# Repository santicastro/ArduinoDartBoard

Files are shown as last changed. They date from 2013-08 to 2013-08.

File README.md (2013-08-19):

ArduinoDartsBoard
=================

Electronic darts board controlled by Arduino Mini Pro. It's o a very early development status. Only cricket game is implemented and has some bugs.

I built the software and the pcb from scratch. I'll upload the pcb diagrams as soon as I can.

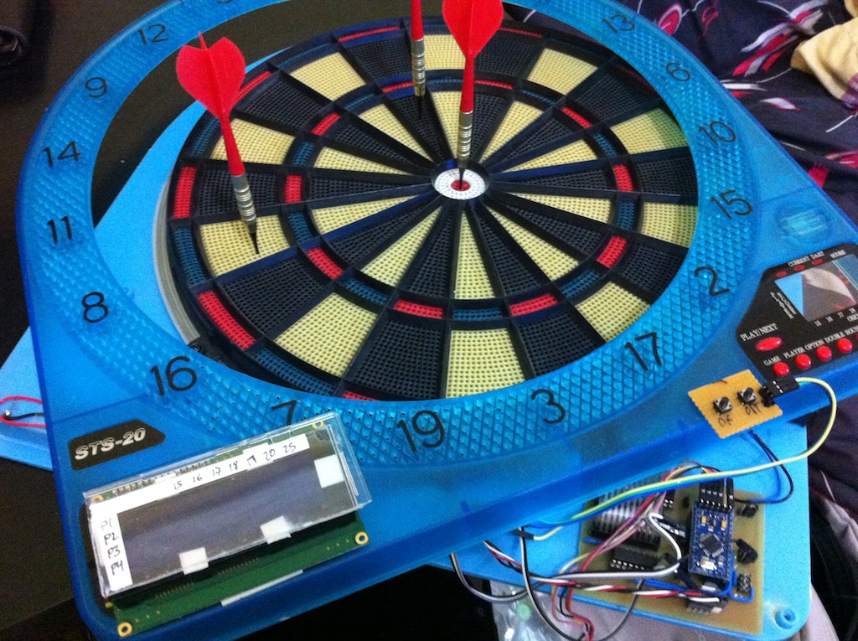
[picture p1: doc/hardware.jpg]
hardware

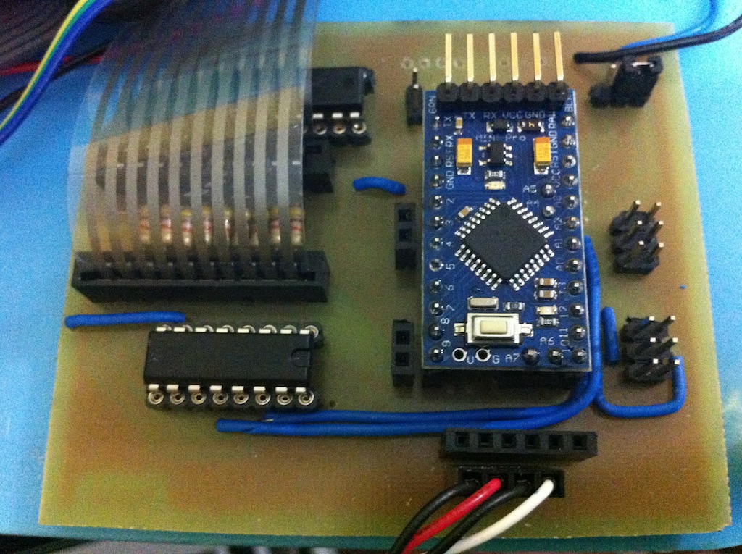
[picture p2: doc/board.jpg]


Sample of the game finished melody: http://www.youtube.com/watch?v=AD7XjPF0V5o

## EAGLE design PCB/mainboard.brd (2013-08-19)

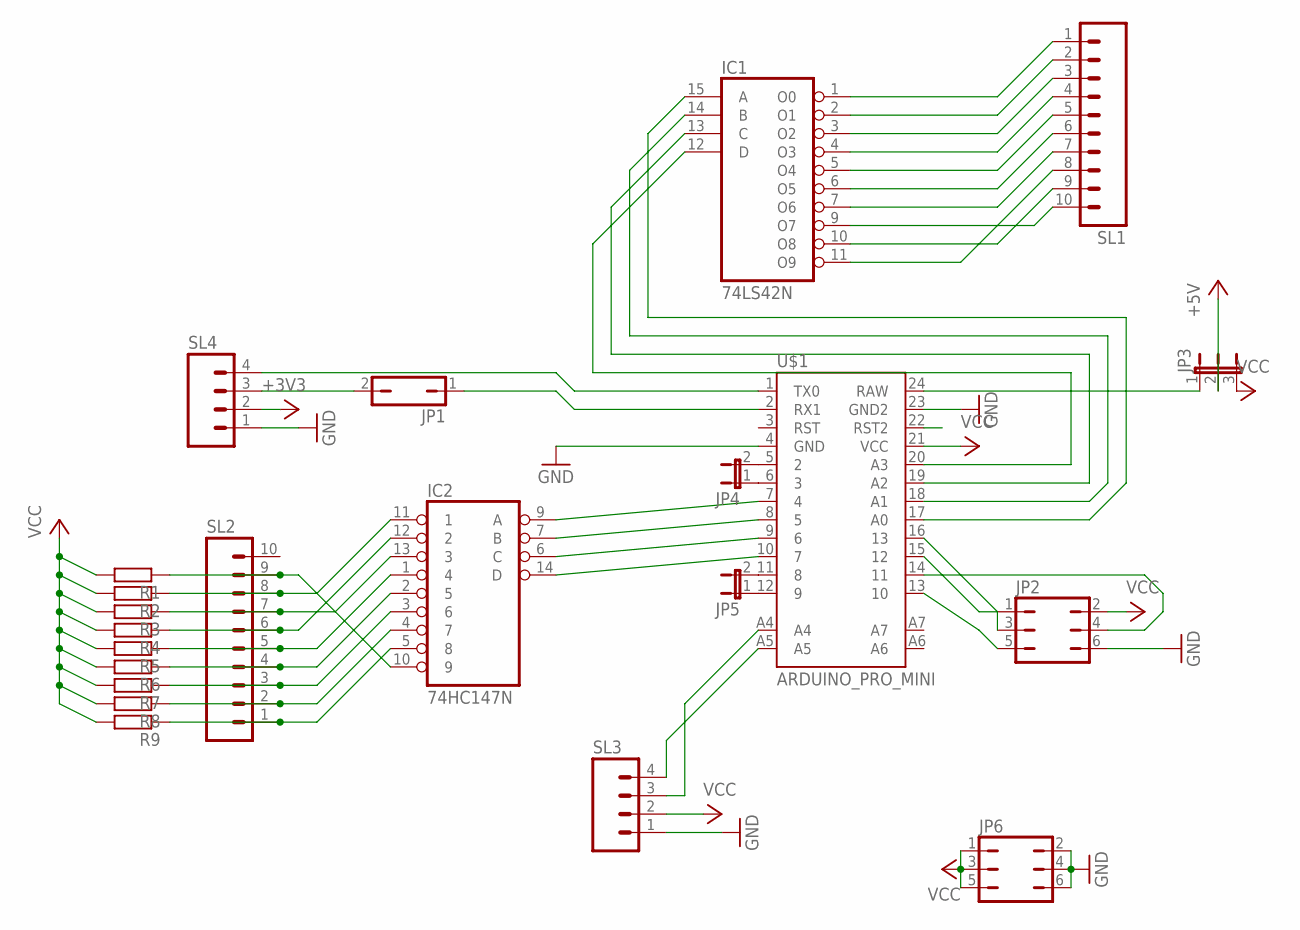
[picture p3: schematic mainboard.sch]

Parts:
IC1: 74LS42N; DIL16
IC2: 74HC147N; DIL16
JP1: JP1Q; JP1
JP2, JP6: JP3Q
JP3: JP2E; JP2
JP4, JP5: JP1E; JP1
R1, R2, R3, R4, R5, R6, R7, R8, R9: R-EU_0204/7; 0204/7
SL1, SL2: M10; 10P
SL3, SL4: M04; 04P
U$1: ARDUINO_PRO_MINI

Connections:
+3V3: SL4.2
+5V: JP3.2
GND: IC1.8 (GND), IC2.8 (GND), JP2.6, JP6.2, JP6.4, JP6.6, SL3.1, SL4.1, U$1.4 (GND), U$1.23 (GND2)
unnamed: IC2.2 (5), R6.1, SL2.4
unnamed: IC2.1 (4), R5.1, SL2.5
unnamed: IC2.12 (2), R4.1, SL2.6
unnamed: IC2.5 (8), R9.1, SL2.1
unnamed: IC2.4 (7), R8.1, SL2.2
unnamed: IC2.3 (6), R7.1, SL2.3
unnamed: IC2.13 (3), R3.1, SL2.7
unnamed: IC2.11 (1), R2.1, SL2.8
unnamed: IC2.10 (9), R1.1, SL2.9
unnamed: IC1.15 (A), U$1.17 (A0)
unnamed: IC1.14 (B), U$1.18 (A1)
unnamed: IC1.13 (C), U$1.19 (A2)
unnamed: IC1.12 (D), U$1.20 (A3)
unnamed: IC1.9 (O7), SL1.10
unnamed: IC1.10 (O8), SL1.9
unnamed: IC1.11 (O9), SL1.8
unnamed: IC2.9 (A), U$1.7 (4)
unnamed: IC1.1 (O0), SL1.1
unnamed: IC1.2 (O1), SL1.2
unnamed: IC1.3 (O2), SL1.3
unnamed: IC1.4 (O3), SL1.4
unnamed: IC1.5 (O4), SL1.5
unnamed: IC1.6 (O5), SL1.6
unnamed: IC1.7 (O6), SL1.7
unnamed: IC2.7 (B), U$1.8 (5)
unnamed: IC2.6 (C), U$1.9 (6)
unnamed: IC2.14 (D), U$1.10 (7)
unnamed: SL3.4, U$1.A5
unnamed: SL3.3, U$1.A4
unnamed: SL4.4, U$1.1 (TX0)
unnamed: JP1.2, SL4.3
unnamed: JP1.1, U$1.2 (RX1)
unnamed: JP2.1, U$1.15 (12)
unnamed: JP2.3, U$1.16 (13)
unnamed: JP2.5, U$1.13 (10)
unnamed: JP2.4, U$1.14 (11)
unnamed: JP3.1, U$1.24 (RAW)
unnamed: JP4.1, U$1.6 (3)
unnamed: JP4.2, U$1.5 (2)
unnamed: JP5.1, U$1.12 (9)
unnamed: JP5.2, U$1.11 (8)
VCC: IC1.16 (VCC), IC2.16 (VCC), JP2.2, JP3.3, JP6.1, JP6.3, JP6.5, R1.2, R2.2, R3.2, R4.2, R5.2, R6.2, R7.2, R8.2, R9.2, SL3.2, U$1.21 (VCC)

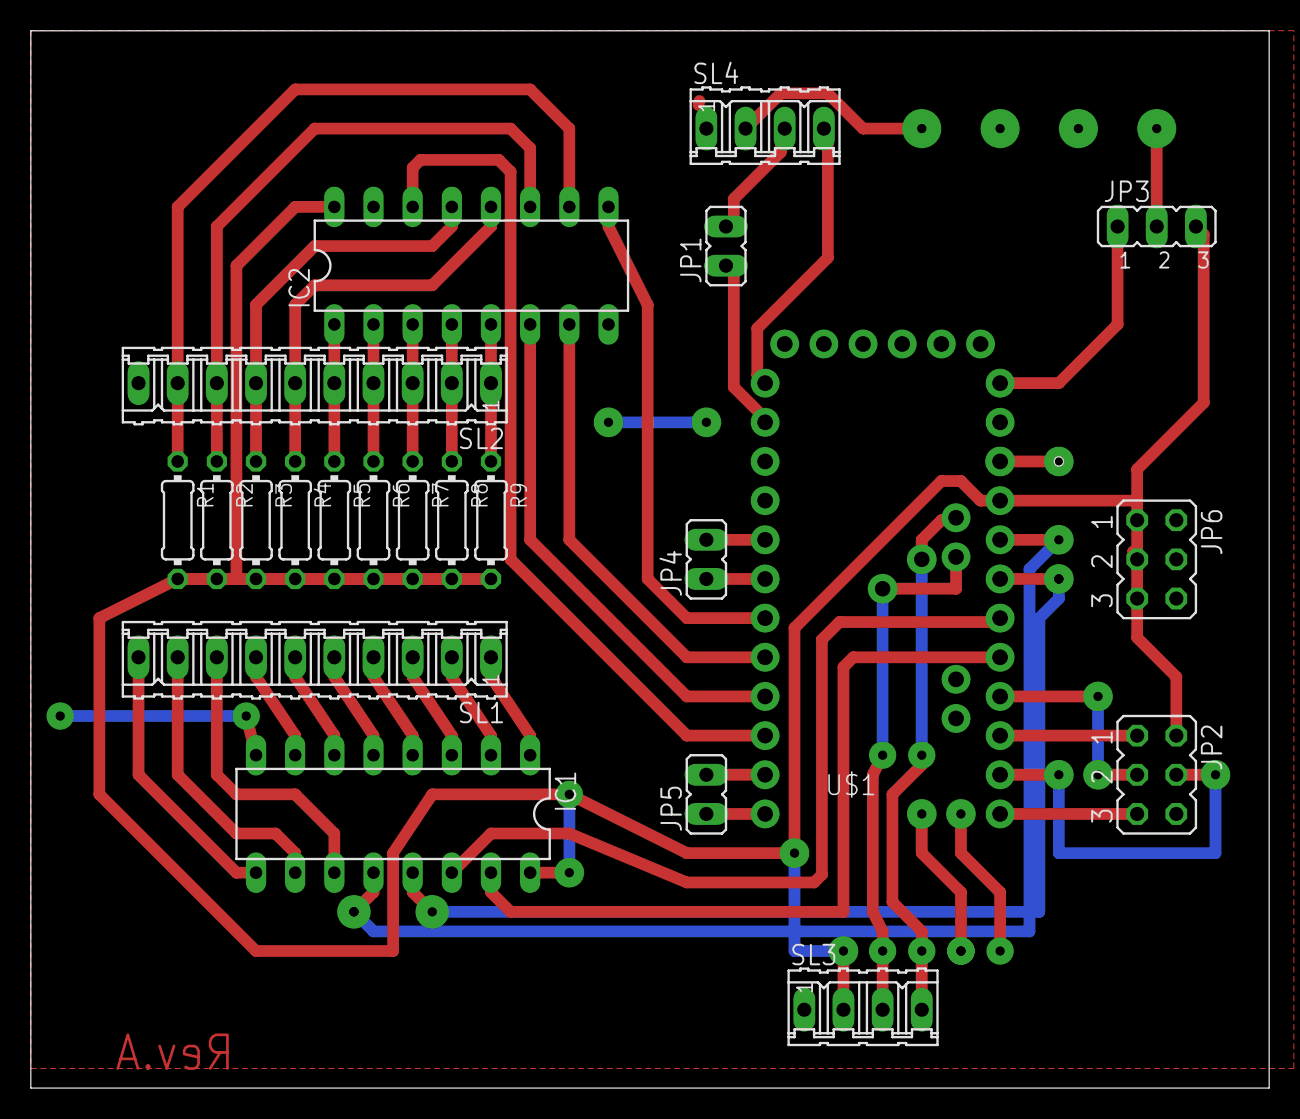
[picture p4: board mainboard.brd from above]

Board: 2 copper layers, 80.3 x 68.6 mm, 22 parts (0 on the bottom side), 43 nets.

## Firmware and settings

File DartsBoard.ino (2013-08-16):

#include <LiquidCrystal.h>
#include <Wire.h>

const int NONE=0;

int inPins[] = {
  4, 5, 6, 7};
int outPins[] = {
  A0, A1, A2, A3};


typedef struct button {
  byte value;
  byte type;
};

// type values are
#define DOUBLE_BUTTON 1
#define TRIPLE_BUTTON 2
#define NORMAL_BUTTON 4
#define INTERNAL_BUTTON 12 //8 + 4, so it's also normal button
#define EXTERNAL_BUTTON 20 // 16 + 4

struct button buttons[169];

int player_count = 2, current_player;

LiquidCrystal lcd(0x0);

byte char_0_hits[8] = { 
  B00000, B00000, B00000, B00000, B00000, B00000, B00000, B00000 };
byte char_1_hits[8] = { 
  B10000, B01000, B01000, B00100, B00100, B00010, B00010, B00001 };
byte char_2_hits[8] = { 
  B10001, B01010, B01010, B00100, B00100, B01010, B01010, B10001 };
byte char_3_hits[8] = { 
  B11111, B11011, B11011, B10101, B10101, B11011, B11011, B11111 };
byte char_selection[8] = { 
  B10000, B01000, B00100, B00010, B00010, B00100, B01000, B10000 };
byte char_dart[8] = { 
  B01010, B11011, B01110, B01110, B01110, B01110, B00100, B00100 };
#define SELECTION_CHAR 4
#define DART_CHAR 5

#define BUTTON_NEXT 2
#define BUTTON_OPTION 3
void setup() {
  int i;
  for(i=0; i<4; i++){
    pinMode(outPins[i], OUTPUT);
    pinMode(inPins[i], INPUT);
  }
  pinMode(BUTTON_NEXT, INPUT);
  digitalWrite(BUTTON_NEXT, HIGH);
  pinMode(BUTTON_OPTION, INPUT);
  digitalWrite(BUTTON_OPTION, HIGH);
  Serial.begin(9600);
  Serial.println("started");

  lcd.begin(20, 4);
  lcd.createChar(0, char_0_hits);
  lcd.createChar(1, char_1_hits);
  lcd.createChar(2, char_2_hits);
  lcd.createChar(3, char_3_hits);
  lcd.createChar(SELECTION_CHAR, char_selection);
  lcd.createChar(DART_CHAR, char_dart);

  lcd.setCursor(0,0);
  lcd.print("-= Darts =-");

  setupButtonMatrix();

  setupSounds();
  // playWin();
  //mapButtons();
  startGame();
}

int readButtons(){
  if(digitalRead(BUTTON_NEXT)==LOW){
    return BUTTON_NEXT;
  }
  if(digitalRead(BUTTON_OPTION)==LOW){
    return BUTTON_OPTION;
  }
  return NONE;
}


void loop() {
  loopCricket();
}

void buttonTest(){
  int button;
  button=readMatrix();
  if(button!=NONE){
    lcd.setCursor(0,2);
    lcd.print(button);
    lcd.print("    ");

    lcd.setCursor(0,3);
    struct button b=buttons[button];
    lcd.print(b.value);
    lcd.print(' ');
    lcd.print(b.type);
    lcd.print(' ');

    //Serial.println(button);
    delay(200);
  }
}

int readMatrix(){
  int row, input;
  for(row=0; row<10; row++){
    // Write row
    PORTC = (PINC & B11110000) | row;
    delayMicroseconds(50);
    // Read columns
    input = ((PIND & B11110000) >> 4) ^ B1111 ;
    // Reset rows
    if(input!=0){ //this means that a button is pressed
      PORTC = (PINC & B11110000);
      return row<<4 | input;      
    }
  }
  PORTC = (PINC & B11110000);
  return 0;
}


void mapButtons(){
  int  last_code=0, code=0;

  // To map the buttons press the one showing on LCD and after finish replace the initialization
  // function with the text received on serial port");
  for(byte value=1; value<=20; value++){
    lcd.setCursor(0,0);
    lcd.print("-- "); 
    lcd.print(value);
    lcd.print(" double   "); 
    // read double value
    while(code == last_code || code==0){
      code = readMatrixW();
      delay(50);
    }
    last_code = code;
    printInitCode(value, code, DOUBLE_BUTTON);

    lcd.setCursor(0,0);
    lcd.print("-- "); 
    lcd.print(value);
    lcd.print(" external   "); 
    // read double value
    while(code == last_code || code==0){
      code = readMatrixW();
      delay(50);
    }
    last_code = code;
    printInitCode(value, code,  EXTERNAL_BUTTON);

    lcd.setCursor(0,0);
    lcd.print("-- "); 
    lcd.print(value);
    lcd.print(" triple    "); 
    // read double value
    while(code == last_code || code==0){
      code = readMatrixW();
      delay(50);
    }
    last_code = code;
    printInitCode(value, code,  TRIPLE_BUTTON);

    lcd.setCursor(0,0);
    lcd.print("-- "); 
    lcd.print(value);
    lcd.print(" internal   "); 
    // read double value
    while(code == last_code || code==0){
      code = readMatrixW();
      delay(50);
    }
    last_code = code;
    printInitCode(value, code,  INTERNAL_BUTTON);
  }
}

void printInitCode(byte value, byte code, byte buttonType){
  Serial.print("button btn");
  Serial.print(code);
  Serial.print(" = {");
  Serial.print(value);
  Serial.print(",");
  Serial.print(buttonType);
  Serial.println("};");

  Serial.print("buttons[");
  Serial.print(code);
  Serial.print("] = btn");
  Serial.print(code);
  Serial.println(";");
}

int readMatrixW(){
  int val=0;
  //read internal value
  while(val==0){
    val = readMatrix();
  }  
  lcd.setCursor(0,3);
  lcd.print(val);
  return val;
}



///////////////////////////////////////////////////////
///// CRICKET GAME
///////////////////////////////////////////////////////

#define P15 0
#define P16 1
#define P17 2
#define P18 3
#define P19 4
#define P20 5
#define P25 6

struct score{
  int points;
  byte cells[7];
};

int getCellIndex(byte value){
  if(value==25){
    return P25;
  }
  else if(value>=15 && value<=20){
    return value-15;
  }
  return -1;
}

struct score scores[4];
int shootCount=3;

void startGame(){
  shootCount=0;

//  scores[0].points = 75;
//  for(int i=P15; i<P25; i++){
//    scores[0].cells[i]=3;
//  }
//  scores[0].cells[P25] = 2;
//
//
//  scores[1].points = 15;
//  for(int i=P15; i<P25; i++){
//    scores[1].cells[i]=3;
//  }
//  scores[1].cells[P25] = 2;

  lcd.clear();
  lcd.setCursor(0,0);
  lcd.print("    -= Cricket =-   ");
  lcd.setCursor(0,1);
  lcd.print("No. of players: ");
  lcd.print(player_count);

  lcd.setCursor(0,3);
  lcd.print("Starting...");
  playTheme();
  printScores();
}

boolean turnFinished(){
  return shootCount==3;
}

void loopCricket(){
  unsigned long time;
  while(true){
    if(gameFinished()){
      shootCount=3;
      showResults();
      if(checkFunctionButtons()!=NONE){
        asm volatile ("  jmp 0");
      }
    }
    else if(turnFinished()){
      //blink
      if(millis()-time<850){
        lcd.noDisplay();
      }
      else {
        lcd.display();
        if(millis()-time>1500){
          time = millis();
        }
      }
      checkFunctionButtons();
    }
    else{
      lcd.display();
      boolean wait = true;
      while(wait){
        int code = readMatrix();
        if(code!=0){
          addShoot(buttons[code]);
          wait=false;
        }
        if(checkFunctionButtons()!=NONE){
          wait=false;
          ;
        }
      }
    }
  }
}
int checkFunctionButtons(){
  int code = readButtons();
  if(code!=NONE){
    if(code==BUTTON_OPTION){
      Serial.println("paso");
      addShoot(buttons[0]);
    }
    else if(code==BUTTON_NEXT){
      nextTurn(); 
    }
    delay(5);
    while(code==readButtons()){
      delayMicroseconds(50);
    }
  }
  return code;
}

void showResults(){
  int winnerIndex=0;
  boolean already_played=false;
  for(int player=1; player<player_count; player++){
    if(scores[player].points>scores[winnerIndex].points){
      winnerIndex = player;
    }
    unsigned long time;
    boolean state=true;
    printScores();
    while(true){
      if(millis()-time<1250){
        if(state==false){
          state=true;
          for(int player = 0; player< player_count; player++){
            lcd.setCursor(6,player);
            if(player==winnerIndex){
              lcd.print("Winner !!!    "); 
            }
            else{
              lcd.print("Loser !!!     "); 
            }
          }
        }
        if(!already_played){
          playWin();
          already_played=true;
        }
      }
      else if(millis()-time < 2500){
        if(state=true){
          state=false;
          printScores();
        }
      }
      else{
        time=millis();
        state=false; 
      }
      if(checkFunctionButtons()!=NONE){
        asm volatile ("  jmp 0");
      }
      delay(50);
    }
  }

}


void addShoot(struct button but){
  if(shootCount<3){
    boolean sound_failed = true;
    int sound_multiplier = 0;
    if(but.value==0){ // do nothing
    }
    else{

      int cellIndex=getCellIndex(but.value);
      if(cellIndex>=0){
        //calculate multiplier
        int multiplier = 1;
        if(but.type & TRIPLE_BUTTON){
          multiplier = 3;
        }
        else if(but.type & DOUBLE_BUTTON){
          multiplier = 2;
        }
        sound_multiplier = multiplier;

        int sum = scores[current_player].cells[cellIndex] + multiplier;
        if(sum>3){
          scores[current_player].cells[cellIndex] = 3;
          multiplier = sum-3;

          if(!allClosed(cellIndex)){
            scores[current_player].points += but.value*multiplier;
            sound_failed=false;
          }

        }
        else{
          scores[current_player].cells[cellIndex] = sum;
          sound_failed=false;
        }
      }
    }
    shootCount++; 
    if(sound_failed){
      playDartFail(1);  
    }
    else{
      playDartOk(sound_multiplier);
    }
    printScores();

  }
}

boolean allClosed(int cellIndex){
  int player;
  for(player=0; player<player_count; player++){
    if(scores[player].cells[cellIndex]<3){
      return false;
    }  
  }
  return true;
}

boolean gameFinished(){
  int player;
  for(player=0; player<player_count; player++){
    for(int i=P15; i<=P25; i++){
      if(scores[player].cells[i]!=3){
        return false;
      }
    }
  }
  return true;
}


void nextTurn(){
  if(gameFinished())
    return;
  current_player = (current_player + 1) % player_count;
  shootCount=0;
  printScores();
}

void printScore(struct score sc, int lineNumber, boolean current){
  lcd.setCursor(0, lineNumber);
  if(current){
    lcd.write(byte(SELECTION_CHAR));
  }
  else{
    lcd.print(' ');
  }
  if(sc.points<1000){
    lcd.print(' ');
  }
  if(sc.points<100){
    lcd.print(' ');
  }
  if(sc.points<10){
    lcd.print(' ');
  }
  lcd.print(sc.points);
  lcd.print(' ');
  lcd.write(byte(sc.cells[P15]));
  lcd.print(' ');
  lcd.write(byte(sc.cells[P16]));
  lcd.print(' ');
  lcd.write(byte(sc.cells[P17]));
  lcd.print(' ');
  lcd.write(byte(sc.cells[P18]));
  lcd.print(' ');
  lcd.write(byte(sc.cells[P19]));
  lcd.print(' ');
  lcd.write(byte(sc.cells[P20]));
  lcd.print(' ');
  lcd.write(byte(sc.cells[P25]));
}

void printScores(){
  lcd.clear();
  int player;
  for(player=0; player<player_count; player++){
    printScore(scores[player], player, current_player==player);
  }
  if(shootCount<3){
    lcd.setCursor(19,3);
    lcd.write(byte(DART_CHAR));
  }
  if(shootCount<2){
    lcd.setCursor(19,2);
    lcd.write(byte(DART_CHAR));
  }
  if(shootCount<1){
    lcd.setCursor(19,1);
    lcd.write(byte(DART_CHAR));
  }
}

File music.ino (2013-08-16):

/* Play Melody
 * -----------
 *
 * Program to play a simple theme_melody
 *
 * Tones are created by quickly pulsing a speaker on and off 
 *   using PWM, to create signature frequencies.
 *
 * Each note has a frequency, created by varying the period of 
 *  vibration, measured in microseconds. We'll use pulse-width
 *  modulation (PWM) to create that vibration.
 
 * We calculate the pulse-width to be half the period; we pulse 
 *  the speaker HIGH for 'pulse-width' microseconds, then LOW 
 *  for 'pulse-width' microseconds.
 *  This pulsing creates a vibration of the desired frequency.
 *
 * (cleft) 2005 D. Cuartielles for K3
 * Refactoring and comments 2006 clay.shirky@nyu.edu
 * See NOTES in comments at end for possible improvements
 */

// TONES  ==========================================
// Start by defining the relationship between 
//       note, period, &  frequency. 
#define	c	3831	//	261	Hz
#define	d	3401	//	294	Hz
#define	e	3040	//	329	Hz
#define	f	2865	//	349	Hz
#define	g	2558	//	391	Hz
#define	gS	2410	//	415	Hz
#define	a	2273	//	440	Hz
#define	aS	2198	//	455	Hz
#define	b	2146	//	466	Hz
#define	cH	1912	//	523	Hz
#define	cSH	1805	//	554	Hz
#define	dH	1704	//	587	Hz
#define	dSH	1608	//	622	Hz
#define	eH	1517	//	659	Hz
#define	fH	1433	//	698	Hz
#define	fSH	1351	//	740	Hz
#define	gH	1276	//	784	Hz
#define	gSH	1205	//	830	Hz
#define	aH	1136	//	880	Hz
// Define a special note, 'R', to represent a rest
#define  R     0

// SETUP ============================================
// Set up speaker on a PWM pin (digital 9, 10 or 11)
int speakerOut = 9;

void setupSounds() { 
  pinMode(speakerOut, OUTPUT);
}


// Set overall tempo
long tempo = 10000;
// Set length of pause between notes
int pause = 1000;
// Loop variable to increase Rest length
int rest_count = 100; //<-BLETCHEROUS HACK; See NOTES

// Initialize core variables
int tone_ = 0;
int beat = 0;
long duration  = 0;

// PLAY TONE  ==============================================
// Pulse the speaker to play a tone for a particular duration
void playTone() {
  long elapsed_time = 0;
  if (tone_ > 0) { // if this isn't a Rest beat, while the tone has 
    //  played less long than 'duration', pulse speaker HIGH and LOW
    while (elapsed_time < duration) {

      digitalWrite(speakerOut,HIGH);
      delayMicroseconds(tone_ / 2);

      // DOWN
      digitalWrite(speakerOut, LOW);
      delayMicroseconds(tone_ / 2);

      // Keep track of how long we pulsed
      elapsed_time += (tone_);
    } 
  }
  else { // Rest beat; loop times delay
    for (int j = 0; j < rest_count; j++) { // See NOTE on rest_count
      delayMicroseconds(duration);  
    }                                
  }                                 
}

void playMelody(int melody[], int beats[], int lenght){
  //tone(8, 250,500);
  for (int i=0; i<lenght; i++) {
    tone_ = melody[i];
    beat = beats[i];

    duration = beat * tempo; // Set up timing

    playTone(); 
    // A pause between notes...
    delayMicroseconds(pause);
  }

}

// MELODY and TIMING  =======================================
//  theme_melody[] is an array of notes, accompanied by theme_beats[], 
//  which sets each note's relative length (higher #, longer note) 
int theme_melody[] = {  
  cH,  b,  g,  cH,  b,   e,  R,  cH,  c,  g, a, cH };
int theme_beats[]  = { 
  16, 16, 16,  8,  8,  16, 32, 16, 16, 16, 8, 8 }; 
int theme_lenght = sizeof(theme_melody) / sizeof(int); // Melody length, for looping.
void playTheme(){
  playMelody(theme_melody, theme_beats, theme_lenght);
}

int win_melody[] = {  
a, a, a, f, cH, a, f, cH, a, eH, eH, eH, fH, cH, gS, f, cH, a, aH, a, a, aH, 
gSH, gH, fSH, fH, fSH, R, aS, dSH, dH, cSH, cH, b, cH, R, f, gS, f, a, cH, a, 
cH, eH, aH, a, a, aH, gSH, gH, fSH, fH, fSH, R, aS, dSH, dH, cSH, cH, b, cH, 
R, f, gS, f, cH, a, f, c, a };
int win_beats[]  = { 
  
50, 50, 50, 35, 15, 50, 35, 15, 100, 50, 50, 50, 35, 15, 50, 35, 15, 100, 50, 35, 15, 50, 25, 25, 13, 13, 25, 20, 10, 50, 25, 25, 13, 13, 25, 20, 13, 50, 38, 13, 50, 38, 13, 100, 50, 35, 15, 50, 25, 25, 13, 13, 25, 20, 25, 50, 25, 25, 13, 13, 25, 20, 25, 50, 38, 13, 50, 38, 13, 100
}; 
int win_lenght = sizeof(win_melody) / sizeof(int); // Melody length, for looping.
void playWin(){
  playMelody(win_melody, win_beats, win_lenght);  
}

int dartok_melody[] = {   
  cH };
int dartok_beats[]  = {  
  24 }; 
int dartok_lenght = sizeof(dartok_melody) /  sizeof(int); // Melody length, for looping.
void playDartOk(int repeat){
  while(repeat-- > 0){
    playMelody(dartok_melody, dartok_beats, dartok_lenght);
    if(repeat>0){
      delay(10);
    }
  }
}

int dartfail_melody[] = {  
  e};
int dartfail_beats[]  = { 
  24 }; 
int dartfail_lenght = sizeof(dartfail_melody) /  sizeof(int); // Melody length, for looping.
void playDartFail(int repeat){
  while(repeat-- > 0){
    playMelody(dartfail_melody, dartfail_beats, dartfail_lenght);  
    if(repeat>0){
      delay(10);
    }
  }
}
/*
 * NOTES
 * The program purports to hold a tone for 'duration' microseconds.
 *  Lies lies lies! It holds for at least 'duration' microseconds, _plus_
 *  any overhead created by incremeting elapsed_time (could be in excess of 
 *  3K microseconds) _plus_ overhead of looping and two digitalWrites()
 *  
 * As a result, a tone of 'duration' plays much more slowly than a rest
 *  of 'duration.' rest_count creates a loop variable to bring 'rest' theme_beats 
 *  in line with 'tone' theme_beats of the same length. 
 * 
 * rest_count will be affected by chip architecture and speed, as well as 
 *  overhead from any program mods. Past behavior is no guarantee of future 
 *  performance. Your mileage may vary. Light fuse and get away.
 *  
 * This could use a number of enhancements:
 * ADD code to let the programmer specify how many times the theme_melody should
 *     loop before stopping
 * ADD another octave
 * MOVE tempo, pause, and rest_count to #define statements
 * RE-WRITE to include volume, using analogWrite, as with the second program at
 *          http://www.arduino.cc/en/Tutorial/PlayMelody
 * ADD code to make the tempo settable by pot or other input device
 * ADD code to take tempo or volume settable by serial communication 
 *          (Requires 0005 or higher.)
 * ADD code to create a tone offset (higer or lower) through pot etc
 * REPLACE random theme_melody with opening bars to 'Smoke on the Water'
 */

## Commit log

2013-08-17 Added pcb design
    [mainboard.brd, mainboard.sch]
2013-08-19 Modified sketch
    [mainboard.brd]

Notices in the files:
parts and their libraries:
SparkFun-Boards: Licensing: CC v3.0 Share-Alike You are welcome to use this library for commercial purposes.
